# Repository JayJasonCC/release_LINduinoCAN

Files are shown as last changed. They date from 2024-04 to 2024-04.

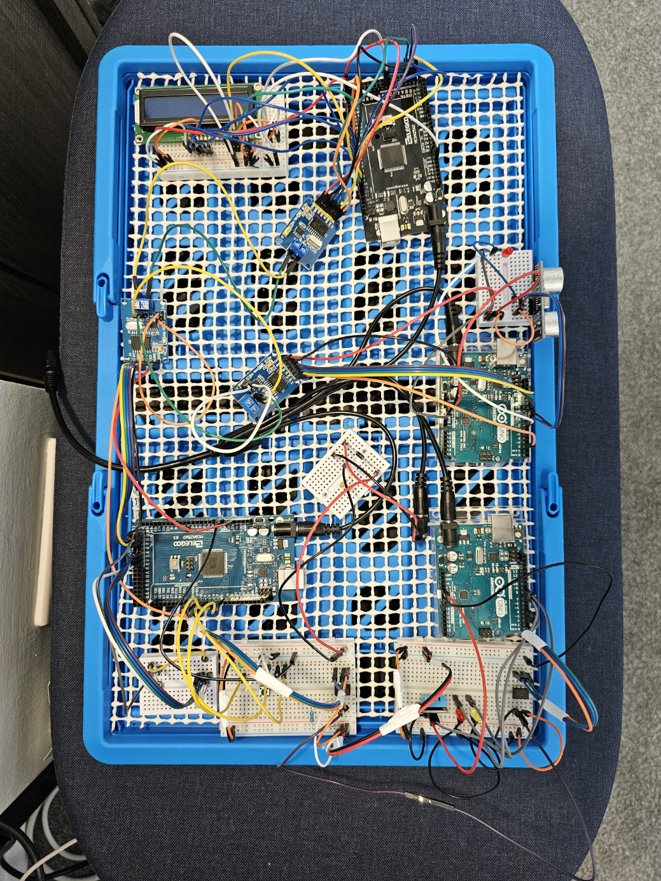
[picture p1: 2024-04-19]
component_CAN&LIN/schematics/20240419_162212.jpg

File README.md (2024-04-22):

<h1 align="right">EXPERIMENTAL</h1>

<h1 align="center"> LINduinoCAN </h1>

<p align="center">
    Developing an experimental platform for vehicular communcation protocols (CAN & LIN) - aiding the development/ testing of novel security proposals for LIN bus.
</p>

---

<p align="center">
  <strong>Contents</strong>
</p>

<p align="center">
    &bull;
  <a href="#introduction-project-outline-objectivs-and-aims">Introduction: Project Outline, Objectivs, and Aims</a> &bull;
  <a href="#repo-structure">Repo Structure</a> &bull;
  <a href="#key-features-capabilities">Key Features/ Capabilities</a> &bull;
  <a href="#getting-started">Getting Started</a> &bull;
  <a href="#dependencies">Dependencies</a> &bull;
  <a href="#bill-of-materials">Bill Of Materials</a>
</p>

---

# Introduction: Project Outline, Objectivs, and Aims

## Project Overview:

Modern vehicles, now sophisticated cyber-physical systems, require complex on-board connectivity to satisfy the requirements of newfound customer demands for innovative features, safety mechanisms, and ADAS functionality. To facilitate this, protocols suchlike CAN, FlexRay and LIN are depended upon. Although ISO sets clear objectives for OEM's and TIERs to work towards sucure-by-design development, one protocol remains vastly used yet untouced by Cyber-Security controls - LIN bus.

Thus, developing an accessible, deployable, and expandable platform for CAN and LIN aims to provide a gateway to further research regarding LIN security mechanisms and the security of vehicular networks as a whole.
 
## Research Objectives:

1.	Investigate widespread vehicular communication protocols, identifying technologies used within systems of differing criticality and function within an automotive context. 
2.	Identify attacks against vehicular communication protocols and its capability to inadvertently affect the vehicle, subsidised with available mitigations and the utilised platforms. 
3.	Develop an experimental platform for CAN and LIN bus capable of implementing CyS proposals for LIN bus and/ or assist in the development of novel approaches to LIN bus security. 
4.  Evaluate the developed platform against previously identified works, while providing scenario-based testing to review its CAN/ LIN communication capabilities and how it addresses accessibility concerns. 

# Repo Structure
> Description of the repo's file structure/ layout

- **component_CAN&LIN** - This folder contains the final projects source code, designs, and schematics to allow simple replication of the developed platform. This reflects checkpoint-3 in phase-3 of the methodology.

- **component_LIN** - This folder holds the source code, designs, and schematics for just the LIN component of the system. Reflecting checkpoint-1 in phase-3 of the methodology.

- **component_CAN** - This folder holds the source code, designs, and schematics for just the CAN component of the system. Reflecting checkpoint-2 in phase-3 of the methodology.

# Key Features/ Capabilities
> Key features of the developed platform. Refering to the 'component_CAN&LIN'
- [x] LIN Communication
- [x] CAN Communication
- [x] CAN and LIN interconnection
- [x] CAN message monitoring
- [x] LIN message monitoring
- [x] Simple deployment
- [x] Easy expandability
- [x] Accessible and affordable

# Getting Started
>  This includes the basic steps to get the platform up and running.

Based on the component you wish to build, obtain the materials required (details in the bill of materials) and assemble as per the provided schematics.
Open the source code using the Arduino IDE, connect each Arduino and flash it with the correct code. Once completed, provide the LIN circuit with minimum 5.5V and maximum 26V supply voltage. The LIN component CANNOT be powered solely from the Arduinos's, since max output is only 5V. The CAN component however can solely be powered using the Arduinos. Crucially, ensure a common ground between LIN nodes is maintained, otherwise sporadic message readings may occur, and that if using more than 2 CAN nodes, the bus is terminated with 120-Ohm resistance.

# Dependencies
>Library dependencies required for the source code.

| Library | git | docs |
| --- |---| --- |
| `DHT.H`  | [git](https://github.com/adafruit/DHT-sensor-library) | [docs](https://learn.adafruit.com/dht) |
| `NewPing.H`  | [git](https://bitbucket.org/teckel12/arduino-new-ping/wiki/Home) | [docs](https://www.arduino.cc/reference/en/libraries/newping/) |
| `Mcp2515.H & SPI.H`  | [git](https://github.com/autowp/arduino-mcp2515) | [docs](https://www.arduino.cc/en/Reference/SPI) |
| `LiquidCrystal.H`  | [git](https://github.com/arduino-libraries/LiquidCrystal) | [docs](https://www.arduino.cc/en/Reference/LiquidCrystal) |
> View attached docs for specifics

# Bill of Materials
> Find below the bill of materials for 'component_CAN&LIN'.

| Amount | MN (manufacturer number) | MPN (manufacturer part number) | Part Type | Properties |
|---|---|---|---|---|
| 3 | Can bus module | pins 13; package THT; variant variant 1; pin spacing 0.1in (2.54mm) | MCP2515, TJA1050 | 8MHz |
| 3 | Arduino Mega 2560 (Rev3) | type Arduino MEGA 2560 (Rev3) | n/a | n/a |
| 1 | Humidity and Temperature Sensor DHT11 | u2 0-50°C; output signal Digital Signal; na DHT11; u3 ±5%RH ±2°C; u1 20-95%RH; dc 3.3-5.5V DC; variant variant 1 | n/a | n/a |
| 1 | Diode | package diode-1n4001; variant pth | n/a | n/a |
| 1 | LCD screen | type Character; pins 16 | n/a | n/a |
| 1 | Red (633nm) LED | polarity common anode; current 0.030A; package 5 mm [THT]; pin order rgb; rgb RGB | n/a | n/a |
| 1 | Red (633nm) LED | color Red (633nm); current 0.030A; leg yes; package 5 mm [THT] | n/a | n/a |
| 1 | Green (555nm) LED | color Green (555nm); current 0.030A; leg yes; package 3 mm [THT] | n/a | n/a |
| 1 | Red (633nm) LED | color Red (633nm); current 0.030A; leg yes; package 3 mm [THT] | n/a | n/a |
| 1 | Yellow (595nm) LED | color Yellow (595nm); current 0.030A; leg yes; package 3 mm [THT] | n/a | n/a |
| 1 | Arduino Uno (Rev3) - ICSP | type Arduino UNO (Rev3) - ICSP (w/o icsp2) | n/a | n/a |
| 2 | MCP2003 | chip label MCP2003; true; pins 8; package DIP (Dual Inline) [THT]; hole size 0.7mm,0.508mm; pin spacing 300mil | n/a | n/a |
| 2 | 120Ω Resistor | resistance 120Ω; tolerance ±5%; power 0.25W; bands 4; package THT; pin spacing 400 mil | n/a | n/a |
| 1 | 1kΩ Resistor | resistance 1kΩ; tolerance ±5%; power 0.25W; bands 5; package THT; pin spacing 400 mil | n/a | n/a |
| 1 | US-100 Ultrasonic Distance Sensor | type ultrasonic distance sensor; variant US-100 | n/a | n/a |
| 4 | Pushbutton | contact resistance 0.1Ω; switch status Pressed; package [THT] | n/a | n/a |

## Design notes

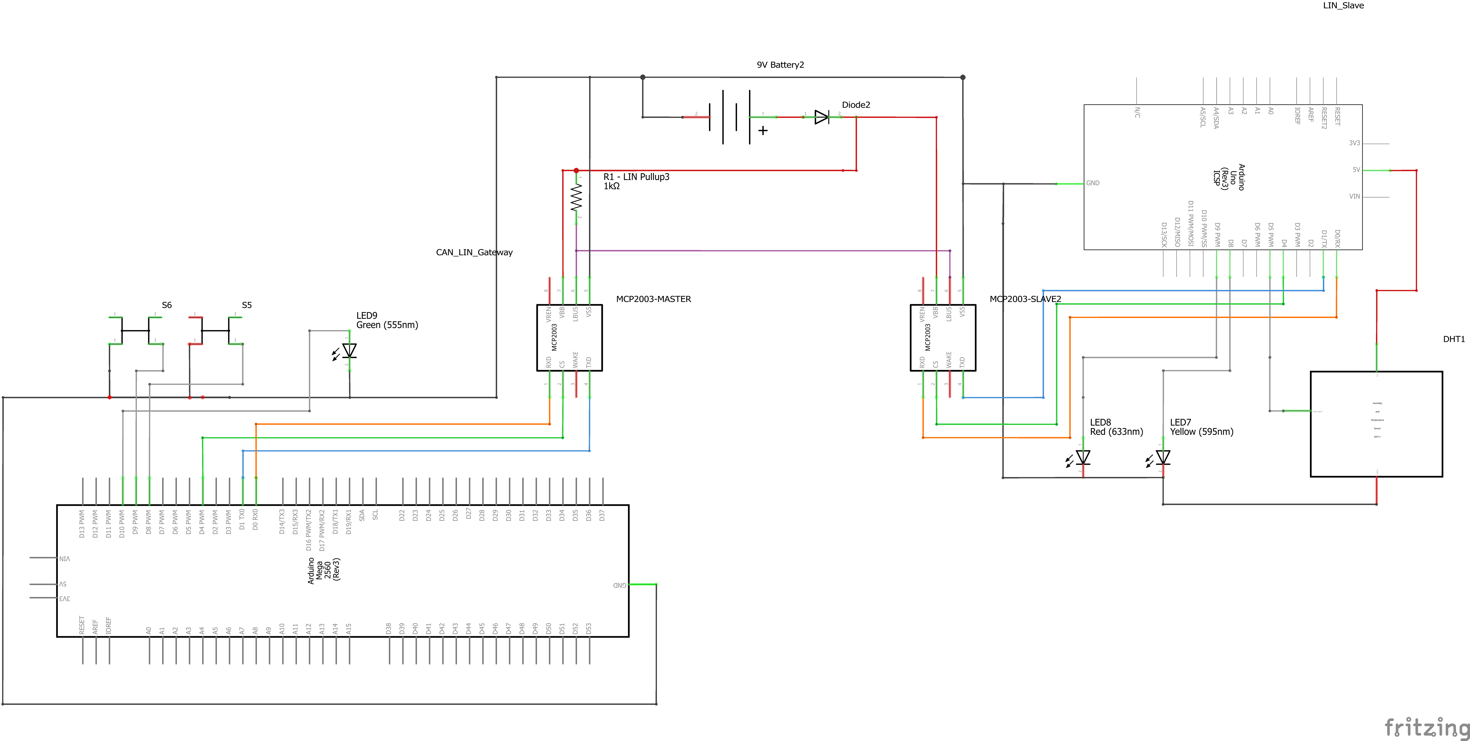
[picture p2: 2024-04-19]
component_LIN/schematics/LIN_plat_schem.png

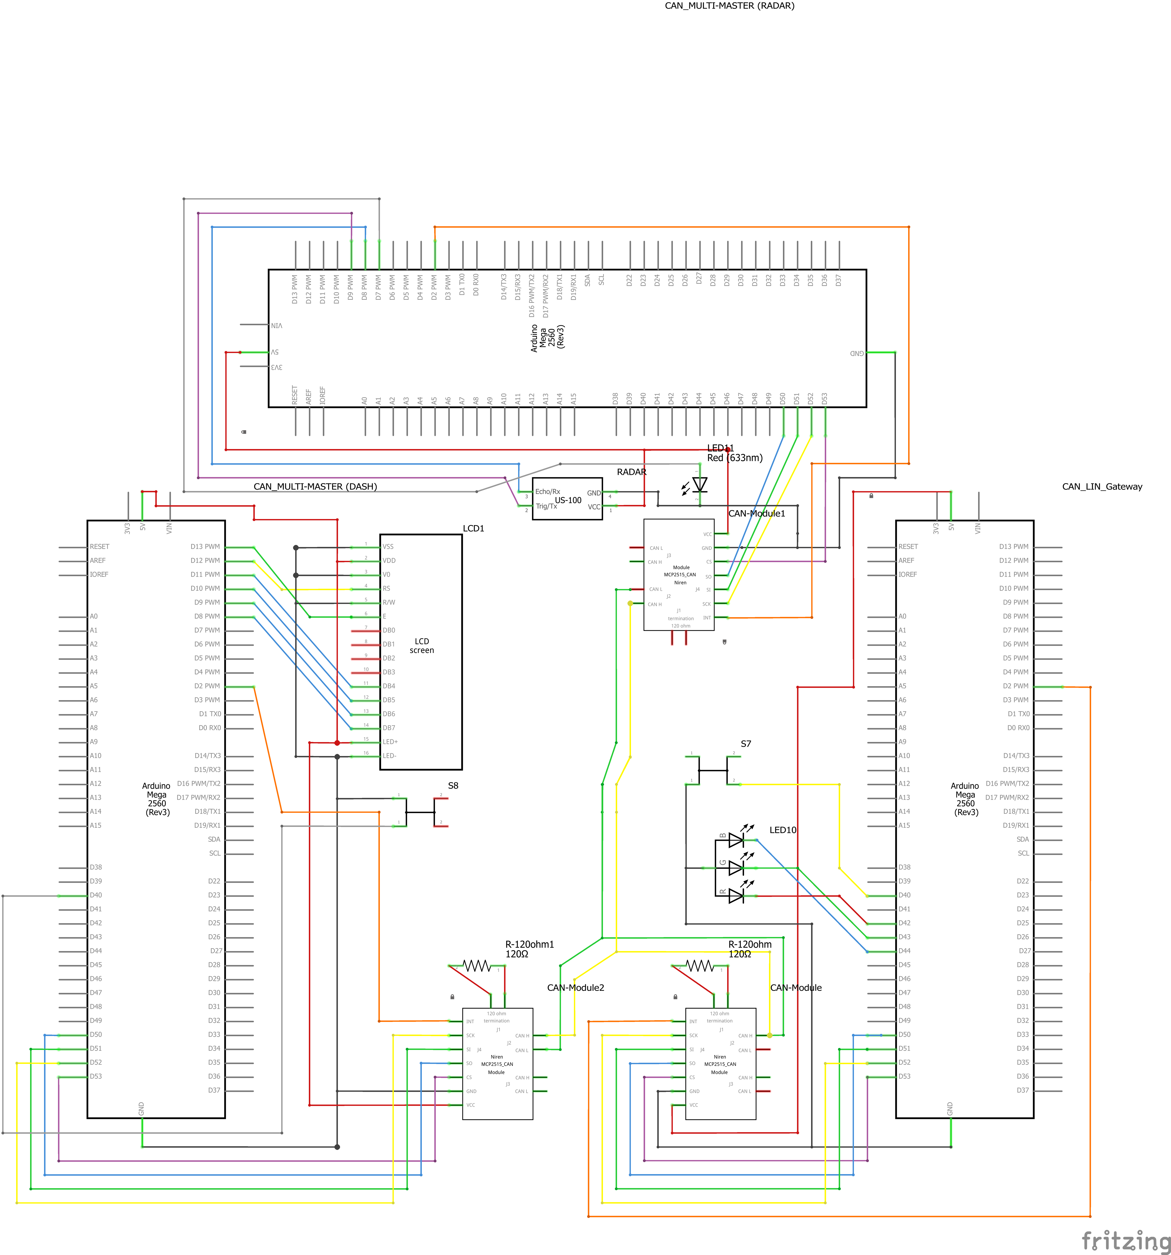
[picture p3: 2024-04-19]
component_CAN/schematics/CAN_ONLY_schem.png

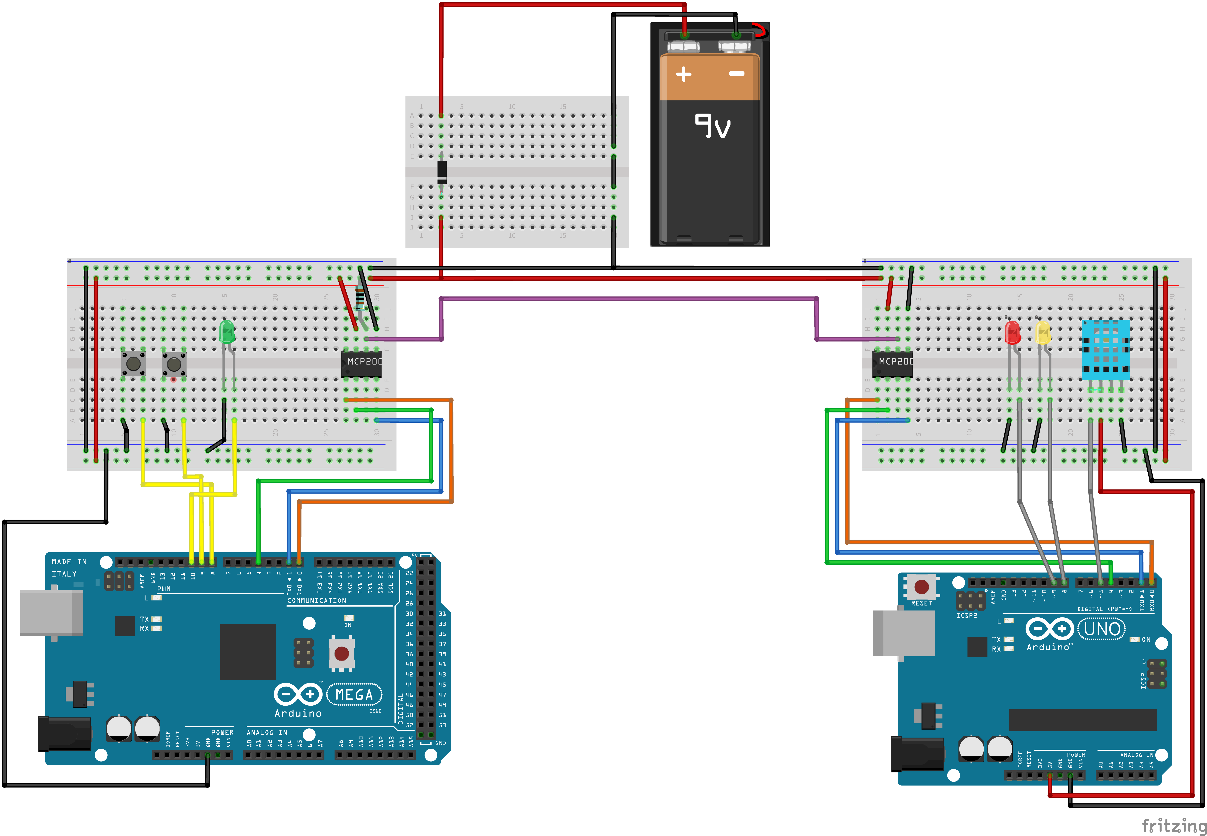
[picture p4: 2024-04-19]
component_LIN/schematics/LIN_plat_bb.png

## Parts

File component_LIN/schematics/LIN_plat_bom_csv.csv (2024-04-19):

Label | Part Type | mn | mpn | part number
9V Battery2 | BC9VPC
CAN_LIN_Gateway | Arduino Mega 2560 (Rev3)
DHT1 | Humidity and Temperature Sensor DHT11
Diode2 | Diode
LED7 | Yellow (595nm) LED
LED8 | Red (633nm) LED
LED9 | Green (555nm) LED
LIN_Slave | Arduino Uno (Rev3) - ICSP
MCP2003-MASTER | MCP2003
MCP2003-SLAVE2 | MCP2003
R1 - LIN Pullup3 | 1kΩ Resistor
S5 | Pushbutton
S6 | Pushbutton
Amount | Part Type | mn | mpn | part number
1 | 1kΩ Resistor
1 | Arduino Mega 2560 (Rev3)
1 | Arduino Uno (Rev3) - ICSP
1 | BC9VPC
1 | Diode
1 | Green (555nm) LED
1 | Humidity and Temperature Sensor DHT11
2 | MCP2003
2 | Pushbutton
1 | Red (633nm) LED
1 | Yellow (595nm) LED

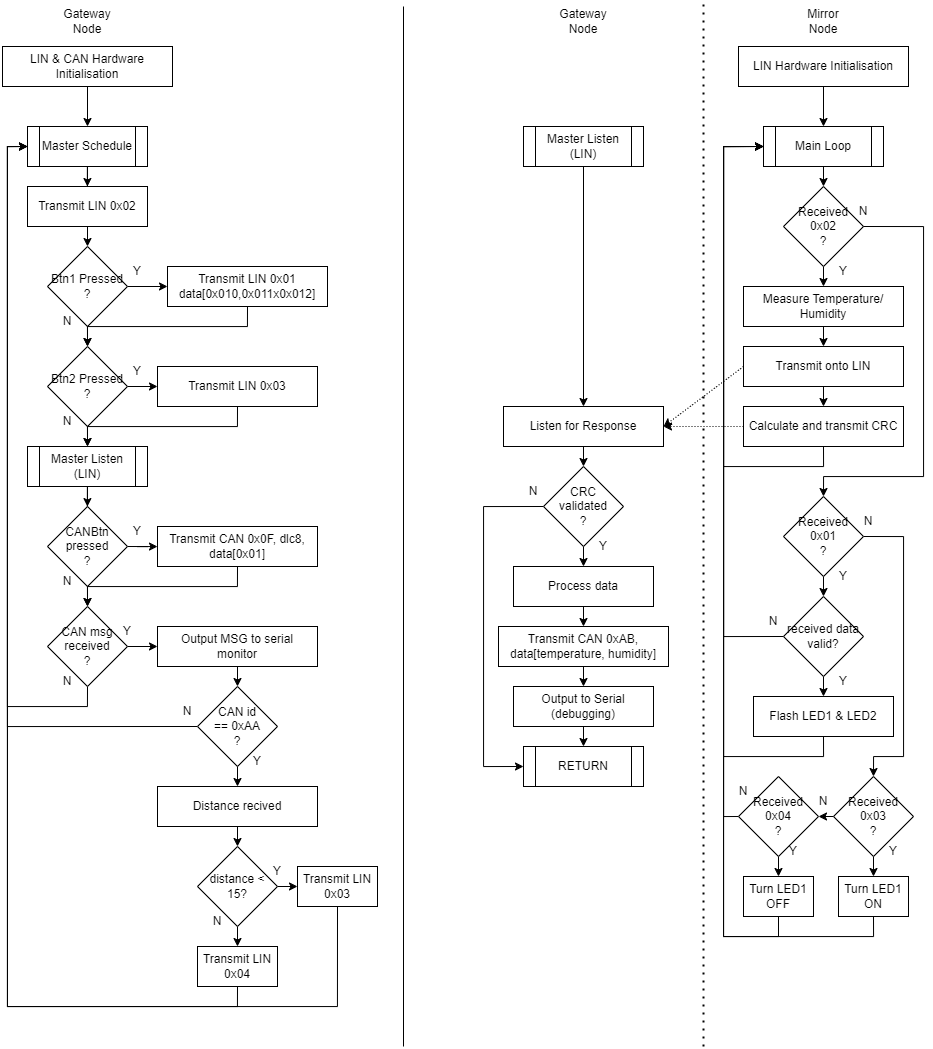
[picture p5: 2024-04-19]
component_CAN&LIN/algorithms/final_gateway_with_mirror.png

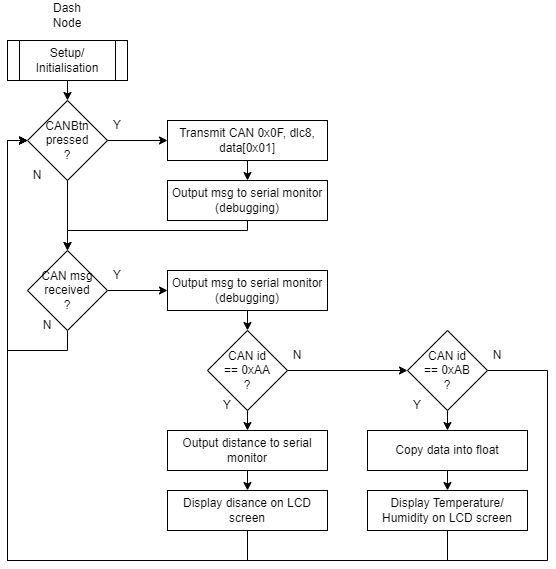
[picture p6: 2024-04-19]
component_CAN&LIN/algorithms/dash.png

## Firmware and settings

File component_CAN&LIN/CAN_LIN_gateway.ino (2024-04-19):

/////////////////////////////////////////// CAN BUS DECLARATIONS/////////////////////////////////////////
#include <SPI.h> // include the SPI library
#include <mcp2515.h> // include the CAN library

struct can_frame canMsg;
MCP2515 mcp2515(53); // CS pin is connected to digital pin 53

const int CANbuttonPin = 40; // pushbutton is connected to digital pin 40

const int RED_PIN = 42; // Arduino pin connected to the red pin on the RGB LED
const int GREEN_PIN = 43; // Arduino pin connected to the green pin on the RGB LED
const int BLUE_PIN = 44; // Arduino pin connected to the blue pin on the RGB LED


//////////////////////////////////////////// LIN BUS DELCARATIONS/////////////////////////////////////////
const int CS = 4; // MCP2003 CS pin
const int buttonPin = 5; // button1 pin
const int buttonPin2 = 6; // button2 pin
const int ledPin1 = 7; // LED1 pin

//declare variables/ constants/ etc
char inByte[9]; // array to store the received data (1Sync, 1ID, 8data, 1checksum)

//declary FACTORY possible counter start positions
const int counter_array[5] = {0x00, 0x10, 0x20, 0x30, 0x40}; // stored counter start points
int start_counter; //global variable to store the counter start point - once definied

//buttons logic 
const unsigned long debounceDelay = 50; // 50ms debounce delay
int buttonState = HIGH;
int lastButtonState = HIGH;
int buttonState2 = HIGH;
int lastButtonState2 = HIGH;

unsigned long lastDebounceTime = 0;

unsigned long previousMillis = 0;  // will store the last time the temperature was requested
const long interval = 2000;  // interval at which to request temperature (milliseconds)

void setup() {
    Serial.begin(9600); // initialize serial communication
    SPI.begin(); // initialize SPI communication

/////////////////////////////////////////// CAN BUS SETUP ///////////////////////////////////////////

    mcp2515.reset();
    mcp2515.setBitrate(CAN_500KBPS, MCP_8MHZ); // set CAN baud rate to 500 kbps (CLASS C CAN NETWORK (High Speed CAN > 125kbp/s)) and Clock 8MHz
    mcp2515.setNormalMode();

    pinMode(CANbuttonPin, INPUT_PULLUP); // set pin as input and enable pull-up resistor

    pinMode(RED_PIN, OUTPUT);
    pinMode(GREEN_PIN, OUTPUT);
    pinMode(BLUE_PIN, OUTPUT);

/////////////////////////////////////////// LIN BUS SETUP ///////////////////////////////////////////

    pinMode(buttonPin, INPUT_PULLUP);
    pinMode(buttonPin2, INPUT_PULLUP);
    pinMode(ledPin1, OUTPUT);

    pinMode(CS, OUTPUT); // set CS pin as output
    digitalWrite(CS, HIGH); // set CS pin to HIGH -> activating MCP2003 (ready mode)
    digitalWrite(ledPin1, HIGH); // turn LED1 on    

    // Initialize the random num gen, using analogue pin 0 as a seed for entropy
    randomSeed(analogRead(0));
    //counter initilisation mechanism
    int randomIndex = random(5); // random number between 0 and 4, since there are 5 possible counter start points
    
    Serial.write(0x55); // send sync byte (01010101) to LIN bus -> would be interpreted by HW
    Serial.write(0x3B); // 0x3B is ID for MASTER counter sync init -> sending this ID forces the SLAVES to receive the counter start point
    for (int i = 0; i < 8; i++) {
        if (i == 0) {
            Serial.write(randomIndex); // send random counter start point to LIN bus
        } else {
            Serial.write(0x00); // padding
        }
    }

    // Access a random element from the array
    int start_counter = counter_array[randomIndex];

    delay(25); // wait for 25ms
    // Flash the LED randomIndex times
    for (int i = 0; i <= randomIndex; i++) {
        digitalWrite(ledPin1, HIGH); // turn LED1 on
        delay(500); // wait for 500ms
        digitalWrite(ledPin1, LOW); // turn LED1 off
        delay(500); // wait for 500ms before next flash
    }

    previousMillis = millis();  // initialize previousMillis

    digitalWrite(ledPin1, LOW); // ensure LED1 is off at the end of setup phase
}

///////////////////////// MASTER TRANSMIT FUNCTIONS //////////////////////////

//function for when transmitting data over LIN (primarlily used for the debug/ test button)
void master_transmit_data(byte id, byte data[], int dataSize){
    Serial.write(0x55); // send sync byte to LIN bus (01010101)
    Serial.write(id); // send ID to LIN bus
    if (dataSize > 0) { // only send data if arraySize is greater than 0
        for (int i = 0; i < 8; i++) { // loop through each byte in data
            if (i < dataSize && data[i] != 0x00) { // if data is not blank
                Serial.write(data[i]); // send DATA to LIN bus
            } else {
                Serial.write(0x00); // send padding byte
            }
        }
    }
}

// function for standard LIN operation, transmits sync and ID, no data -> slave(s) would respond accordingly
void master_transmit(byte id){
    Serial.write(0x55); // send sync byte to LIN bus (01010101)
    Serial.write(id); // send ID to LIN bus
}

///////////////////////// BUTTON HANDLING FUNCTIONS //////////////////////////

// Function to handle button debounce
bool debounceButton(int buttonPin, int &buttonState, int &lastButtonState, unsigned long &lastDebounceTime) {
    int reading = digitalRead(buttonPin);
    if (reading != lastButtonState) {
        lastDebounceTime = millis();
    }
    if ((millis() - lastDebounceTime) > debounceDelay) {
        if (reading != buttonState) {
            buttonState = reading;
            return true;
        }
    }
    lastButtonState = reading;
    return false;
}

// Function to handle button press with data
void handleButton(int buttonPin, int &buttonState, int &lastButtonState, unsigned long &lastDebounceTime, byte id, byte data[], int dataSize) {
    if (debounceButton(buttonPin, buttonState, lastButtonState, lastDebounceTime) && buttonState == LOW) {
        master_transmit_data(id, data, dataSize);
    }
}

// Overloaded function to handle button press without data
void handleButton(int buttonPin, int &buttonState, int &lastButtonState, unsigned long &lastDebounceTime, byte id) {
    if (debounceButton(buttonPin, buttonState, lastButtonState, lastDebounceTime) && buttonState == LOW) {
        master_transmit(id);
    }
}

///////////////////////////// MASTER LISTENING FUNCTION ///////////////////////////////

// returns true if checksum is validated
bool master_validate_checksum(byte data[], int dataSize){
    byte checksum = 0; // initialize checksum
    for (int i = 0; i < dataSize - 1; i++) { // loop through each byte in data, except the last one
        checksum += data[i]; // add to checksum
    }
    // Calculate checksum: invert the 8-bit sum of all bytes
    checksum = ~checksum;

    // Compare calculated checksum with received checksum
    if (checksum == data[dataSize - 1]) {
        // Checksum is correct, data is valid
        return true;
    } else {
        // Checksum is incorrect, data is invalid
        return false;
    }
}

void master_listen(){
    
    if (Serial.available() >= 1) { /// changin this from 2 to 1 -> allows for odd num  of bytes
        Serial.readBytes(inByte,1);
        switch (inByte[0]){
            case 0x55: // if the sync is detected, the next must be the ID
                Serial.readBytes(inByte,1);
                switch (inByte[0]) {
                    case 0x02: // if ID is 0x02 -> itself in this case
                        Serial.readBytes(inByte,9); // or changing it to read 9 bytes... ONLY ON MASTER
                        
                        // if master_validate_checksum function returns true (passing the inByte array and its size as arguments)
                        // sending the DATA and the CHECKSUM (8 bytes of data, 1 checksum byte)
                        if (master_validate_checksum(inByte, 9)) {
                            // do this, if true (if the checksum is correct)
                            digitalWrite(ledPin1, HIGH);
                            //delay(500);
                            digitalWrite(ledPin1, LOW);

                        // Print the inByte array's contents in hexadecimal format
                        for (int i = 0; i < 9; i++) {
                            Serial.print(inByte[i], HEX);
                            Serial.print(" "); // optional: print a space for readability
                        }
                        Serial.println(); // print a newline for readability
                        }

                        float temp, humidity;

                        // Copy the first 4 bytes from inByte to temp
                        memcpy(&temp, inByte, 4);

                        // Copy the next 4 bytes from inByte to humidity
                        memcpy(&humidity, inByte + 4, 4);

                        // Print the temperature and humidity (debugging purposes)
                        Serial.print("Temperature: ");
                        Serial.println(temp);
                        Serial.print("Humidity: ");
                        Serial.println(humidity);

                        // to send over CAN
                        byte CANdata[8]; // array to store the data to be sent over CAN

                        memcpy(CANdata, &temp, 4); // copy the temperature to the first 4 bytes of CANdata
                        memcpy(CANdata + 4, &humidity, 4); // copy the humidity to the next 4 bytes of CANdata

                        //setup can message structure
                        canMsg.can_id  = 0xAB; // CAN id of the message
                        canMsg.can_dlc = 8; // Data length of the message
                        memcpy(canMsg.data, CANdata, 8); // Copy the data into the CAN message

                        mcp2515.sendMessage(&canMsg); // Send CAN message

                        // Print the CAN message to the serial monitor (debugging purposes)
                        Serial.print("CAN message sent: ID = 0x");
                        Serial.print(canMsg.can_id, HEX);
                        Serial.print(", Data = 0x");
                        for (int i = 0; i < canMsg.can_dlc; i++) {
                            Serial.print(canMsg.data[i], HEX);
                        }
                        Serial.println();
                        break;
                break;
        }
    }
}}


void loop() {

    //scheduling table consists of the temp and humidity request every 2 seconds

    /////////// LIN BUS ///////////

    unsigned long currentMillis = millis();

    if (currentMillis - previousMillis >= interval) {
        // save the last time the temperature was requested
        previousMillis = currentMillis;

        // request temperature by sending 0x02 as the ID
        master_transmit(0x02);
    }

    byte id = 0x01; //id
    byte data[] = {0x10, 0x11, 0x12}; //data
    int dataSize = sizeof(data);
    handleButton(buttonPin, buttonState, lastButtonState, lastDebounceTime, id, data, dataSize);

    byte id3 = 0x03;
    handleButton(buttonPin2, buttonState2, lastButtonState2, lastDebounceTime, id3);
    
    master_listen(); // listen for response -> function performs required action

    /////////// CAN BUS ///////////

    // this is the debug/ test button for comms
    if (digitalRead(CANbuttonPin) == LOW) { // If button is pressed
        Serial.println("Button pressed."); // Print a message to the serial monitor

        canMsg.can_id  = 0x0F; // CAN id of the message
        canMsg.can_dlc = 8; // Data length of the message
        canMsg.data[0] = 0x01; // Data to be sent
        mcp2515.sendMessage(&canMsg); // Send CAN message

        // Print the CAN message to the serial monitor
        Serial.print("CAN message sent: ID = 0x");
        Serial.print(canMsg.can_id, HEX);
        Serial.print(", Data = 0x");
        for (int i = 0; i < canMsg.can_dlc; i++) {
        Serial.print(canMsg.data[i], HEX);
        }
        Serial.println();

        delay(1000); // Delay to debounce the button
  }


    if (mcp2515.readMessage(&canMsg) == MCP2515::ERROR_OK) { // If a CAN message is received
        Serial.print("Received CAN message with ID: 0x");
        Serial.print(canMsg.can_id, HEX);
        Serial.print(", Data: 0x");
        for (int i = 0; i < canMsg.can_dlc; i++) {
            if (canMsg.data[i] < 0x10) { // Print leading zero for single-digit hex values
                Serial.print('0');
            }
            Serial.print(canMsg.data[i], HEX);
        }
        Serial.println();

        if (canMsg.can_id == 0xAA && canMsg.can_dlc >= 2) { // Check if the message has the correct ID and data length
            int distance = (canMsg.data[0] << 8) | canMsg.data[1]; // Combine the high and low bytes into the distance value
            Serial.print("Distance = ");
            Serial.println(distance);

            // perform actions based on distance measurement
            if (distance < 15) {
                // send LIN command to toggle (blindspot monitoring) LED
                master_transmit(0x03); // send LIN command to turn on LED

                //debugging lights purposes
                analogWrite(RED_PIN, 255);
                analogWrite(GREEN_PIN, 0);
                analogWrite(BLUE_PIN, 0);
            } else {
                // send LIN command to toggle (blindspot monitoring) LED
                master_transmit(0x04); // send LIN command to turn off LED

                //debugging lights purposes
                analogWrite(RED_PIN, 0);
                analogWrite(GREEN_PIN, 50);
                analogWrite(BLUE_PIN, 0);
            }
        }
    }
}

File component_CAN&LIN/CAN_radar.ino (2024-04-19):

//this is the CAN radar code for the LINduinoCAN project

#include <SPI.h> // include the SPI library
#include <mcp2515.h> // include the CAN library
#include <NewPing.h> // include the Ultrasonic sensor library

struct can_frame canMsg;
MCP2515 mcp2515(10); // CS pin is connected to digital pin 10

#define TRIGGER_PIN  9  // Arduino pin tied to trigger pin on the ultrasonic sensor.
#define ECHO_PIN     8 // Arduino pin tied to echo pin on the ultrasonic sensor.
#define MAX_DISTANCE 500 // Maximum distance we want to ping for (in centimeters). Maximum sensor distance is rated at 400-500cm.

unsigned int prevDistance = 0; // Previous distance measured by the ultrasonic sensor
#define N 25 // Number of measurements to average
unsigned int measurements[N]; // Array to hold measurements
unsigned int sum = 0; // Sum of measurements
unsigned int index = 0; // Index of oldest measurement

NewPing sonar(TRIGGER_PIN, ECHO_PIN, MAX_DISTANCE); // NewPing setup of pins and maximum distance.

void setup() {
    Serial.begin(9600);
    SPI.begin(); // initialize SPI communication

    mcp2515.reset();
    mcp2515.setBitrate(CAN_500KBPS, MCP_8MHZ); // set CAN baud rate to 500 kbps and Clock 8MHz
    mcp2515.setNormalMode();

    pinMode(7, OUTPUT); // LED connected to digital pin 7

    // Initialize measurements array and sum
    for (int i = 0; i < N; i++) {
      measurements[i] = 100; // initialises array with 100's instead of 0's
      sum += measurements[i];
    }
}

void loop() {
  if (mcp2515.readMessage(&canMsg) == MCP2515::ERROR_OK) { // If a CAN message is received (for debugging purposes)
    Serial.print("Received CAN message with ID: 0x");
    Serial.print(canMsg.can_id, HEX);
    Serial.print(", Data: 0x");
    for (int i = 0; i < canMsg.can_dlc; i++) {
      if (canMsg.data[i] < 0x10) { // Print leading zero for single-digit hex values
        Serial.print('0');
      }
      Serial.print(canMsg.data[i], HEX);
    }
    Serial.println();

    // 0x0F is the comms test message -> flashes LED
    if (canMsg.can_id == 0x0F) { // If the message has ID 0x0F
      digitalWrite(7, HIGH); // Turn on the LED
      delay(500); // Wait for 500ms
      digitalWrite(7, LOW); // Turn off the LED
    }
  }

  delay(50); // Wait 50ms between pings (about 20 pings/sec). 29ms should be the shortest delay between pings.
  unsigned int uS = sonar.ping(); // Send ping, get ping time in microseconds (uS).
  unsigned int distance = uS / US_ROUNDTRIP_CM; // Convert ping time to distance in cm (US_ROUNDTRIP_CM = 57).

  // Subtract oldest measurement from sum
  sum -= measurements[index];
  // Replace oldest measurement with new one
  measurements[index] = distance;
  // Add new measurement to sum
  sum += measurements[index];
  // Calculate moving average
  unsigned int movingAverage = sum / N;
  // Increment index, wrapping around to 0 if it exceeds N-1
  index = (index + 1) % N;

  // Check if the current distance is different from the previous distance
  if (movingAverage != prevDistance) {
    // Prepare the CAN message
    canMsg.can_id  = 0xAA; // CAN id of the message
    canMsg.can_dlc = 8; // Data length of the message
    canMsg.data[0] = (movingAverage >> 8) & 0xFF; // High byte of distance
    canMsg.data[1] = movingAverage & 0xFF; // Low byte of distance

    // Send the CAN message
    mcp2515.sendMessage(&canMsg);

    // Print the CAN message to the serial monitor (for debugging purposes)
    Serial.print("CAN message sent: ID = 0x");
    Serial.print(canMsg.can_id, HEX);
    Serial.print(", Distance = ");
    Serial.print(movingAverage);
    Serial.println(" cm");

    // Update the previous distance
    prevDistance = movingAverage;
  }
  
}
